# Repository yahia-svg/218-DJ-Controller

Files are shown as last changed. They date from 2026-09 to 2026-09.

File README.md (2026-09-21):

# 218-DJ-Controller
A fully DIY DJ controller. 

**Introduction**
---
`A brief intro about the project and the repository.`
<br>
This is a fully DIY DJ Controller. This repository includes the general 3D design of the DJ controller, some unique independent components, the firmware that runs the device, and the schematic showing the circuit connections that power the DJ Controller. 
**Note:** This project is not complete yet. As a result, you may find missing components and designs still under development.

**Project Status**
---
`This section describes the status of the project and the progress made so far, as it is yet to be completed.`
- The project is still under development; the current version only includes the initial designs and operating systems.
- As expected, a working prototype has not been built
- Currently, the full 3D design and the schematic diagram.

**Materials Table**
---
`This section has a table including all the data about the electronic components needed for building this DJ Controller. The table lists the number of pieces needed for each component (quantity); the type of component/actuator (Type); the exact model name for the component (Module); the total amount of money spent to buy the full quantity of the component (price) aka if we're buying 20 buttons, the "price" is the total money needed to buy all 20 buttons; and finally the link address where you can buy this exact component online (Link).`
| Quantity | Type | Module | Price | Link |
|---|---|:---:|---|---|
|1|Microcontroller|Teensy 4.1 Microcontroller|57 USD|https://devboardsmarket.com/products/teensy-4-1|
|2|Multiplixer|74HC4067 16-Channel Analog Digital Multiplexer|3 USD|https://www.ram-e-shop.com/shop/kit-multiplexer-744067-74hc4067-16-channel-analog-digital-multiplexer-breakout-board-8009|
|15|Rotary Potentiometer|R0902N rotary potentiometer 10kohm|5 USD|https://ar.aliexpress.com/item/1005007976451892.html?gatewayAdapt=glo2ara|
|6|Slide Potentiometer|b103 rotary potentiometer 10kohm|6 USD|https://microohm-eg.com/linear-slide-pot-10k-103-mixer-style-88-mm-body-3-electrical-pins-2-mounting-lugs/|
|4|Rotary Encoder|EC11 Rotary Encoder|2 USD|https://www.ram-e-shop.com/shop/pot-ec11-rotary-5pin-20mm-ec11-rotary-encoder-with-push-button-switch-5pin-20mm-silver-9624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|
|2|Bearing|608ZZ Shielded Miniature Ball Bearing|0.5 USD|https://ampere-electronics.com/product/608zz-shielded-miniature-ball-bearing-8x22x7mm/|
|20|LEDs|NeoPixel 1-bit WS2812 5050 RGB LED Driver|13.4 USD|https://www.ram-e-shop.com/shop/kit-ws2812-single-neopixel-1-bit-ws2812-5050-rgb-led-driver-development-board-8258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|
|50|Resistors|10 kohm Carbon Resistance 1/4W|0.5 USD|https://www.ram-e-shop.com/shop/carbon-resistance-1-4w-price-per-4-resistors-9506#attr=314|
|50|Resistors|220 Carbon Resistance 1/4W|0.5 USD|https://www.ram-e-shop.com/shop/carbon-resistance-1-4w-price-per-4-resistors-9506#attr=314|
|20|Capacitor|Ceramic Capacitor 100nF - 400V (104J400V) Disc 10mm|3 USD|https://ampere-electronics.com/product/ceramic-capacitor-100nf-400v-104j400v-disc-10mm/|
|10|Capacitor|Ceramic Capacitor 1uF - 630v (105J630V) Disc 20mm|1.5 USD|https://ampere-electronics.com/product/ceramic-capacitor-1uf-630v-105j630v-disc-20mm/|
|5|Capacitor|Electrolytic Capacitor 100uF - 50V|0.1 USD|https://ampere-electronics.com/product/electrolytic-capacitor-100uf-50v/|
|5|Capacitor|Electrolytic Capacitor 100uF - 50V|0.1 USD|https://ampere-electronics.com/product/electrolytic-capacitor-10uf-50v/|
|1|Power Supply|Wall Power Adapter 5Vdc 3A|5 USD|https://www.ram-e-shop.com/shop/rpi4-adaptor-onoff-wall-power-adapter-usb-type-c-output-5vdc-3a-with-on-off-switch-7840|
|4|Wires|2mm Electric Copper Wire 11 AWG, 1 Meter ElSewedy Electric|3 USD|https://fluxelectronix.com/shop/electric-copper-wire-2mm-15-awg-1-meter-el-sewedy-electric/|
|1|Screws|Bolt +M3x08 mm (100 Screws/bag)|1 USD|https://www.ram-e-shop.com/shop/nail-3x08mm-bolt-m3x08-mm-100-screws-bag-6546|
|2|Connector|Pin Header Male 1x40|0.1 USD|https://www.ram-e-shop.com/shop/ph1-1x40-male-ph1-pin-header-male-1x40-straight-2-54mm-5808|
|2|...|Breadboard 830|1.2 USD|https://www.ram-e-shop.com/shop/bb01-bread-board-bb-01-breadboard-830-tie-point-6143|
|43|Buttons|DS-430 Push Button Momentary Switch Square Shape 2 Pin|4 USD|https://makerselectronics.com/product/ds-430-push-button-momentary-switch-square-shape-2-pin/|
|1|Connector|Dupont Crimp Connector Kit - 310 Pcs|2.5 USD|https://fluxelectronix.com/shop/dupont-crimp-connector-kit-310pcs/|
|1|Socket|Audio Microphone Female Socket|0.1 USD|https://lampatronics.com/product/audio-microphone-female-socket-jack-japan-6-35mm-6pin-stereo-pj-609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|
|1|Switch|Metal Switch On/Off 12mm|1.5 USD|https://lampatronics.com/product/audio-microphone-female-socket-jack-japan-6-35mm-6pin-stereo-pj-609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|
|1|Cable|Micro USB Cable for Arduino|0.5 USD|https://fluxelectronix.com/shop/micro-usb-cable-for-arduino-30cm-length/|
|2|Connector|Female USB Connector Type(A) DIP|0.1 USD|https://fluxelectronix.com/shop/female-usb-connector-type-a-dip/|
|1|Connector|Female DC Power Plug to 2-Pin|0.1 USD|https://fluxelectronix.com/shop/female-dc-power-plug-to-2-pin-screw-terminal/|
|1|Connector|AUX 3.5mm Female Jack|0.1 USD|https://makerselectronics.com/product/aux-3-5mm-female-jack-solder-connector/|
|2|Magnetic Rotary Position|as5047d|14 USD|https://www.alibaba.com/product-detail/AS5047D-AS5047P-Encoder-Adapter-Board-SimpleFOC_60824124421.html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|
<br>
**Extra Services Used**
---
`This section mentions the extra services or technologies that you will need to utilize to build the project and how/why/for what you will use them.`
| Type | Usage |
|---|---|
|3D printing|Joy Wheels and Performance Pads' Caps|
|CNC Cutting|Cutting the acrylic to form the body of the DJ ControllerZ

---

**Mechanical Analysis**
---
`This section showcases the 3D design of the whole device, allowing you to accurately analyze the mechanical sid of the project.`

This is the 3D model visualizing the design for the DJ Controller. The design showcases the different pads, potentiometers, and encoders.

**Electrical Analysis**
---
`This section includes a detailed analysis of the electrical side of the project through the multitude of schematic designs provided in the section, showcasing the wiring of the circuit and component placement (in the context of circuit connections`

This shows the schematic diagram for the circuit powering the DJ Controller


This shows the schematic diagram for the buttons used in the circuit powering the DJ Controller.


This shows the schematic diagram for the LEDs used in the circuit powering the DJ Controller.

--- 

**Component Analysis**
---
`This section consists of a table that showcases the unique components we used for our project (components); the unique feature available in our project that these components bring (function); and how these components operate or what process they follow to provide these unique features.`
| Component | Function | Operation|
|---|---|---|
|Jog Wheel|Mainly used to control playback|Rotation sends movement data|
|Tempo Fader|Can change track speed + BPM|Moving the slide controls the tempo percentage sent to the software|
|SYNC|Used to match decks easily and automatically|Software adjusts deck based on BPM Analysis|
|Play/Pause|Starts or stops playback|Rotation sends movement data|
|CUE|Sets a cue point and allows return to that point|Button controls sofware actions such as abilities preview|
|Loop IN|Sets starting point for a loop|Marks the beggining of a loop|
|Loop OUT|Sets ending point for a loop|Marks the end of a loop|
|Loop ON/OFF|Used to activate or deactivate loops|Toggles the current loop|
|Loop Size -/+|Used to control or change loop length|Button Changes beats|
|TRIM|Able to control input level|Changes chanell gain|
|HI|Able to control high frequencies|Boosts or cuts treble|
|MID|Able to control middle frequencies|Boosts or cuts vocals|
|LOW|Able to control low frequencies|Boosts or cuts bass|
|Channel Fader|Able to control deck volume|Vertical movement changes volume for chosen channel|
|Channel CUE|Able to preview a deck through headphones|Routes deck to headphones|
|Crossfader|Used to blend both decks (deck 1 and deck 2, aka right side and left side deck)|Controls both decks|
|Master Level|Controls output|Changes final volume|
|Headphone Level|Controls volume of what is heard through headphones|Adjusts headphone volume|
|Master Mix|Controls what is heard through headphones|Assigns each section different values|
|Beat FX Select|Choose effects|Cycle through effects|
|FX Parameter|Controls Effect Intensity|Turning changes parameters for effects|
|Beat -/+|Changes effect timing|Changes effect beat|
|FX ON|Used to activate effects|Toggles the selected effect|
|Smart CFX|Used to apply combined effects|Simoltaneous change of multiple effects|
|Smart Fader|Used as a helping mechanism to automate transitions|Performs changes while transitioning between decks|
|Smart Fader AUTO|Allows automatic transition activation|Excutes Smart Fader Behavior|
|MIC INPUT|Connect Microphone|Audio enters the computer interface|
|MIC LEVEL|Microphone level|Change microphone level|
|MIC ON/OFF|Enables Microphone|Mutes microphone|
|HOT CUE|Used to store playbook points|Works with predefined positions (CUE Positions)|
|PAD FX|Operates effects from pads|Each pad is used to activate a specific effect|
|BEAT JUMP|Used to jump through tracks|Move playback forward and backward based on beat amounts|
|Sampler|Used to play samples|Utilizes stored sounds|
|Performance Pads|Allows Multifunction controls|Behavior changes with selected mode|

---

**Assembly Guide**
---
`You can think of this section as a "Methods" section. Basically, it gives a general guide on how to build this project.`
<br>
**1. Get the electronic components that you will need**
You will need to get all the electronic components that we listed in the materials table above. In addition, it is really important that you get the same number of pieces if you wish to implement this project at the same scale we did.

**2. 3D printing and CNC cutting**
After getting the electronic components, you will be missing some pieces. You will have to get some parts printed first. These are the caps used for the pads and potentiometers. Sure, you could avoid using caps at all, and with that you won't have to print any parts, but having these caps significantly changes how your device looks visually (to the better, of course). Then, it is necessary that you build the body for the controller. We chose to build it using acrylic. If you wish to do the same, then relying on CNC Cutting is the most efficient method to build that body. After cutting the Acrylic into the desired shape, you will probably need to use heating mechanisms to shape into the final required shape.

**3. Placement and Wiring**
Now, you're finally ready to start building; all the things you need are ready. What you need to do now is get the body you're using and place the electronics in their designated places/locations as per the full 3D model provided above. Then, you should start wiring and connecting all the components with the help of the schematic diagrams we provided above.

**Repo Layout**
---
`This section gives you a quick and brief walkthrough of all these files you see in the GitHub repository and what you can expect to see in each file.`
<br>
-Mohamed'sJournal.md contains Mohamed's work and contributions to the device, which include feature selection, BOM, and 3D design of the device's body.

-YAHYA'SJOURNAL.md contains Yahya's contributions, which are mainly focused on the 3D design of the main body, including multiple rendering processes.

-Michael's-Journal.md contains Michael's contributions to the project, which include the initial 2D sketch of the device and writing this README for you to read.

-Moaz's Journal contains Moaz's contributions to the project, which mainly revolve around designing the electronic circuit powering the device by drawing a schematic diagram (like the ones provided above).

-Schem is a folder within the repository that contains all the schematic-related files.

-Zine 1 and Zine 2 are two visual methods of representing the project.

-Acrylic cuts is a folder that contains the acrylic sheet cuts that will be used in the device.
**Plans for next week**
---
`This section gives a brief idea of what we plan to do and accomplish within the next week.`
- Develop firmware
- Finalize Designs for 3D-printed components
- Run final tests to make sure the device is running and operating correctly.

**Expected Project Status**
---
`This section describes the results that we expect to achieve within the time span of the next week, after fulfilling our goals/plans described in the above section (Plans for next week)`
- 3D-printed components' design: Complete
- Circuit analysis: Complete and fully operational
- Project Progress Overall: Complete
- Next Step: IRL Prototype Building

**FAQs**
---
`This section includes the answers to the most commonly discussed topics within or ouside of your main community discussion topics.`
**Why build a DIY DJ Controller?**
<br>
If you love music, it's definitely a great investment. You will get to tune, mix, and use as many effects as you want on your favourite songs/music. In addition, you can just try and explore new stuff using this new device. Now, if you don't love music, it's still really fun to just play with it and do random stuff. Also, it's really cool; just imagine how cool it would be to play DJ for your friends when they come over or just give them the opportunity to play with it for a while. It's just super fun.

**I don't have much experience building stuff. Can I still build this?**
<br>
Definitely yes. We didn't have that much experience ourselves. In fact, I think that this is my first or one of my first ever hardware/electronics projects to work on. So, to answer your question, yes, you can build this yourselves (THis is not an overly optimistic future; it's actually totally realistic.

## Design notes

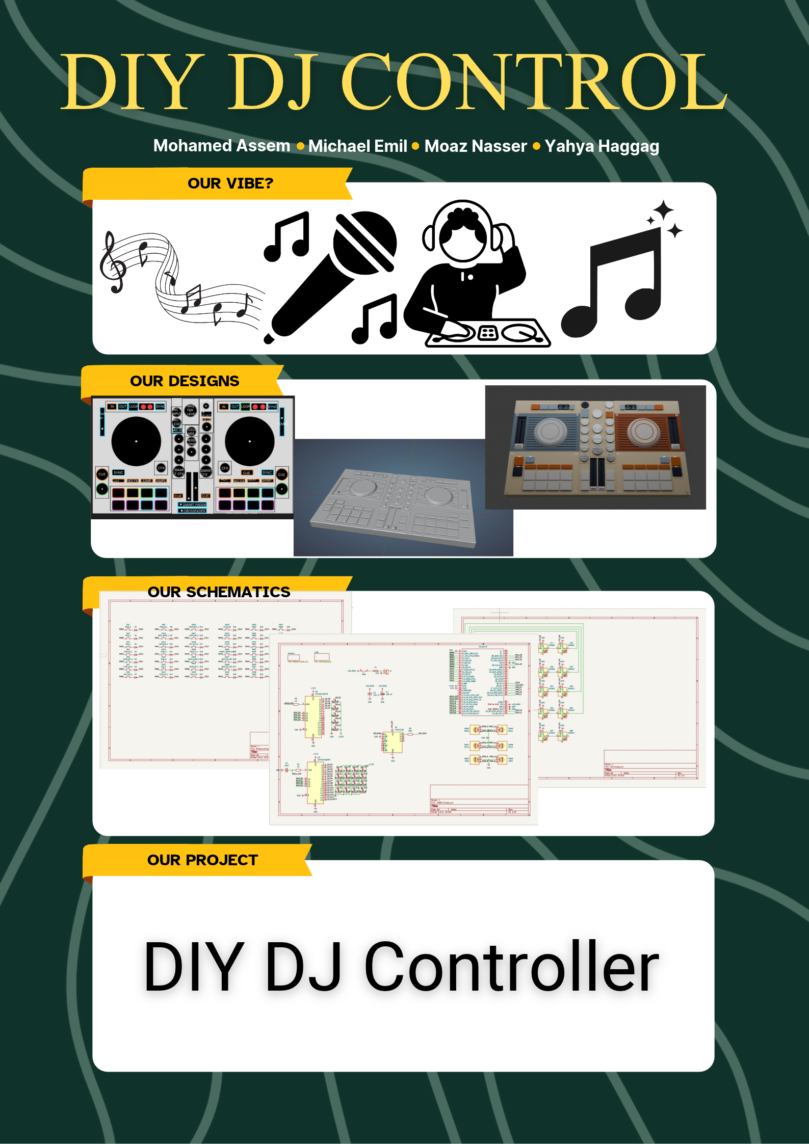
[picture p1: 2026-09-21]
Zine 1.png

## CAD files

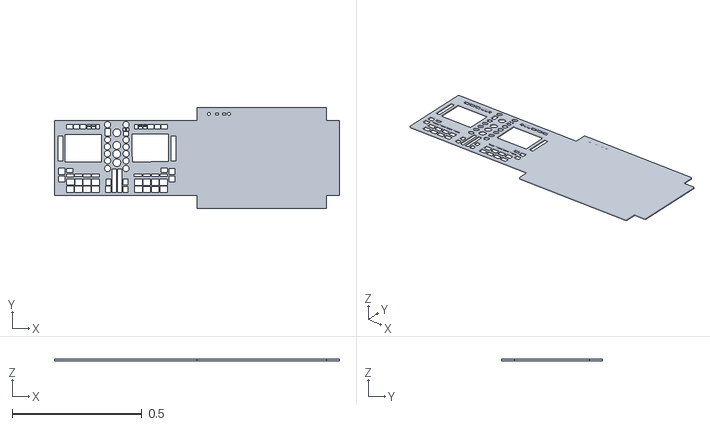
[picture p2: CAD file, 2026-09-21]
acrylic cuts/body.stl
1.10 x 0.39 x 0.006

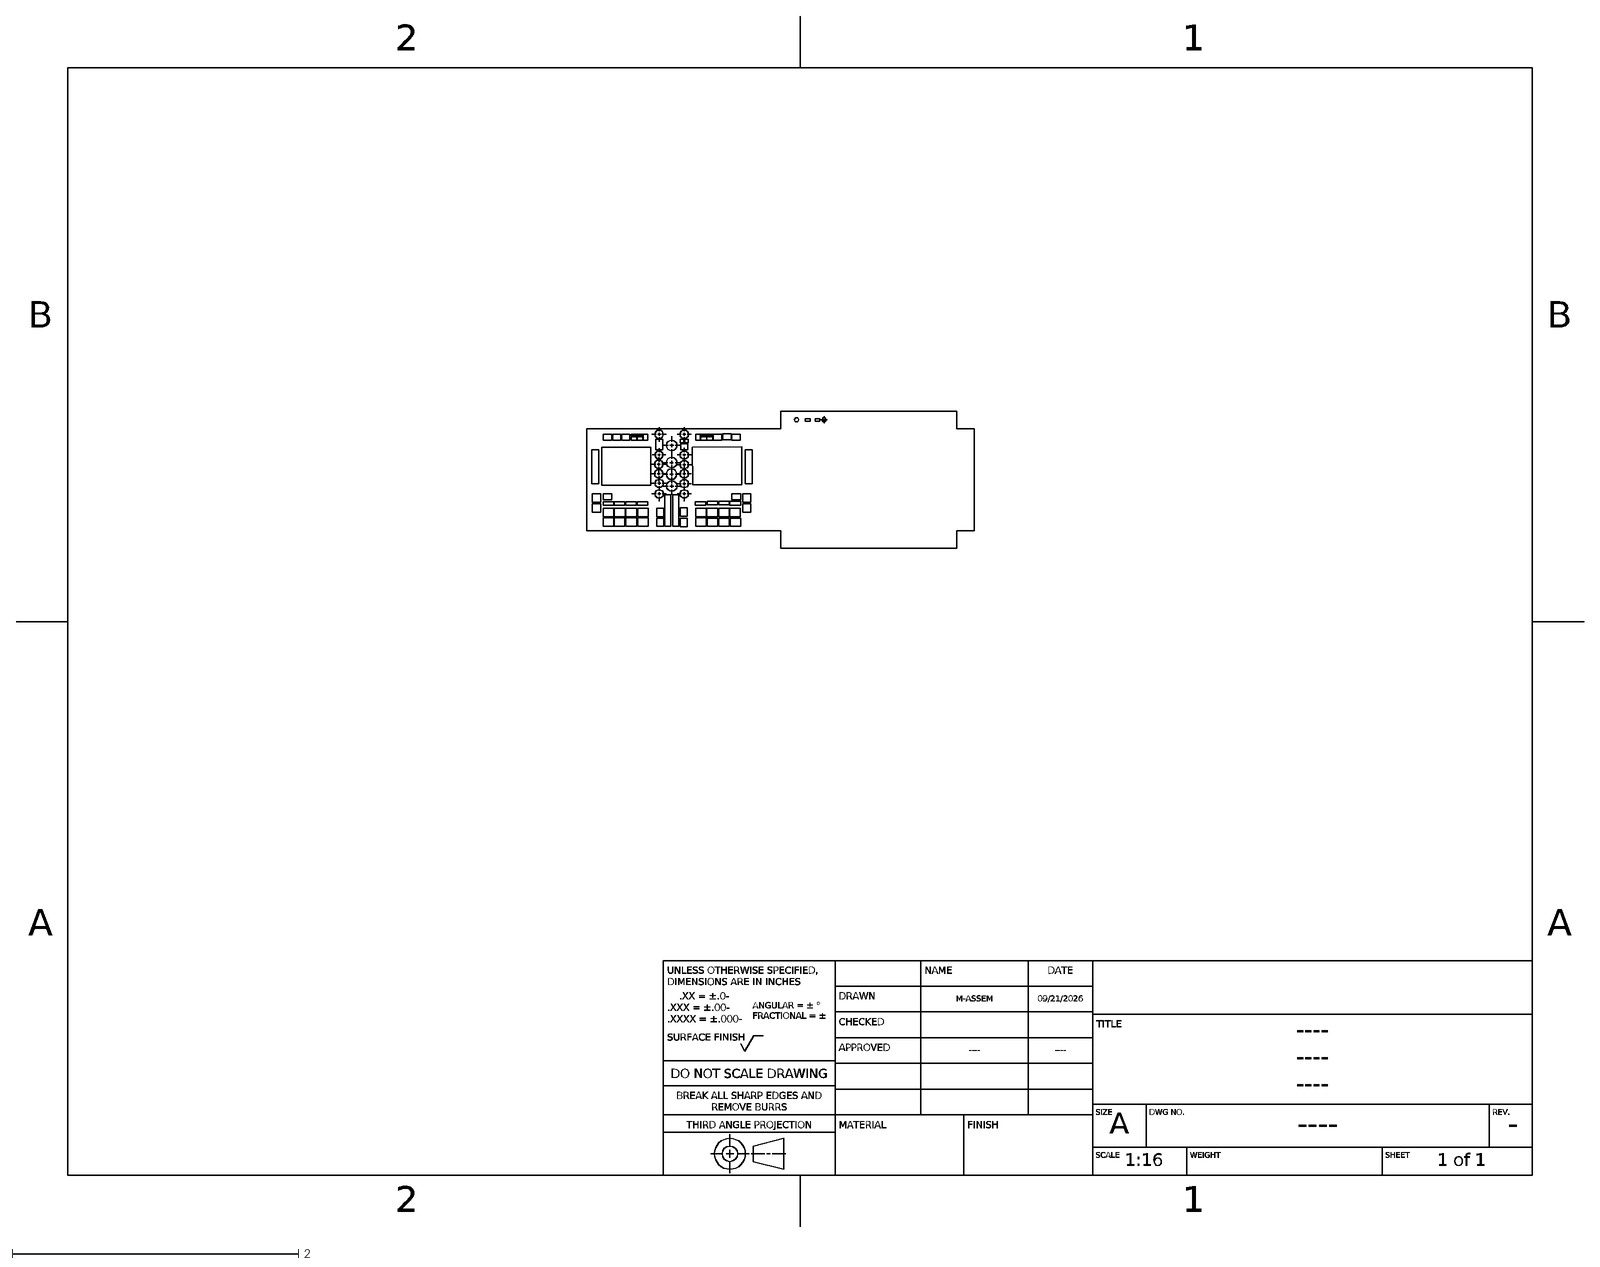
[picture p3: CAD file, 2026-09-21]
acrylic cuts/dj body.dxf
2
1
A
B
UNLESS OTHERWISE SPECIFIED, DIMENSIONS ARE IN INCHES
.XX = ±.0- .XXX = ±.00- .XXXX = ±.000-
ANGULAR = ± ° FRACTIONAL = ±
SURFACE FINISH
DO NOT SCALE DRAWING
BREAK ALL SHARP EDGES AND REMOVE BURRS
THIRD ANGLE PROJECTION
NAME
DATE
DRAWN
M-ASSEM
09/21/2026
CHECKED
APPROVED
----
MATERIAL
FINISH
TITLE
SIZE
DWG NO.
REV.
-
SCALE
1:16
WEIGHT
SHEET
1 of 1

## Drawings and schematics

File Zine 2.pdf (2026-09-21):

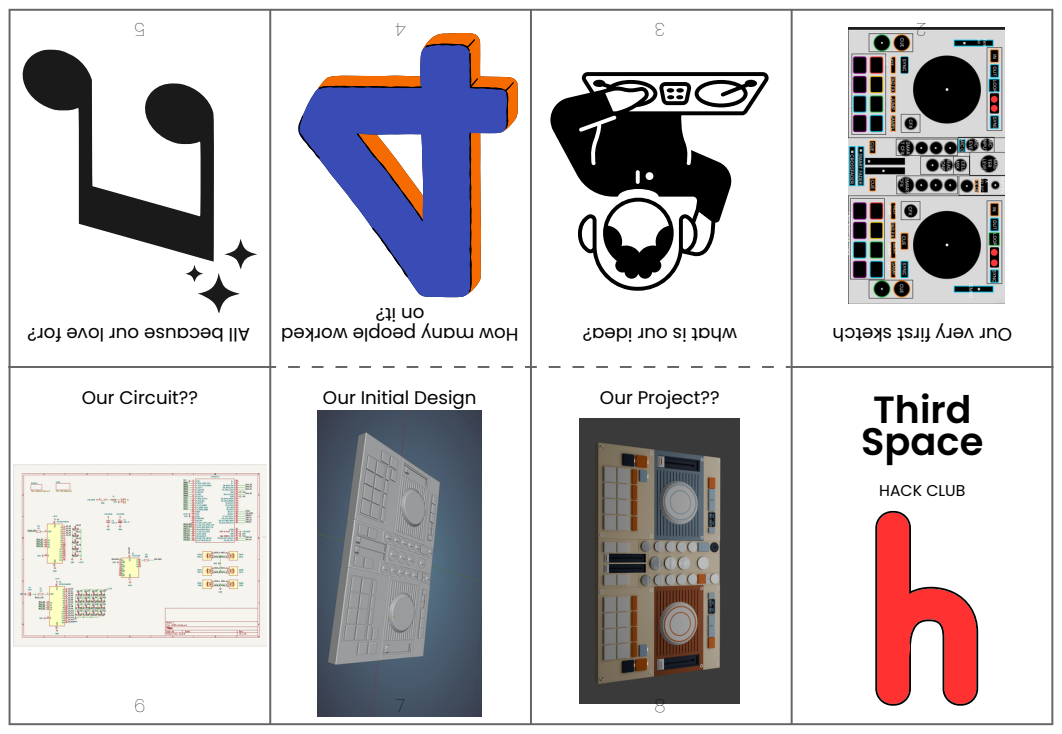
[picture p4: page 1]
Third Space; Our Circuit??; Our Initial Design; Our Project??; HACK CLUB

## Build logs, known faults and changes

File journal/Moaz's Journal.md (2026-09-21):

### 21-9

From all of the work that I can do in this project, I really wanted to make the schematic. It's a relatively new yet a familiar process, I love how intrigued it is, when you do the connections and try to optimize the space and how clear it is, and also I have some small experience with KiCad so it was easy to start working from the beginning. The bill of material wasn't my own mission, yet I helped in it a little bit. As our goal was to create a controller with physical controls and similar to professional ones, it was actually a last minute idea that came to me and my teammate yahia at the same time, so we had to do it.

---

I had multiple problems that involved different solutions even before I started  actually working. My friend decided theta Teensy 4.1 MCU is going to be te best for our use case, as it was used in different audio and music based projects. Having next to zero experience I was struck when I didn't find the symbol for the Teensy in the KiCad default symbol editor. I want on a ([docuemented][https://lapse.hackclub.com/timelapse/hXlyyBR2OCXZ]) run that was resolved by me finding about KiCad symbol libraries, and that I can find any symbol by examining open source, user made symbols, a one that was very useful was [this one][(https://github.com/blackketter/teensy.pretty)] which held the entire library for the Teensy. Also I had 2 options which was either using one large schematic sheets, at the beginning, I found that using multiple schematics is confusing, so I chose the large one, but after working for a while, the sheet was crowded that I had to use multiple ones.

---
I analyzed the BoM, looking at how many buttons, LEDs and everything we need, which helped me plan the "pin assignment", it is summed up in this table:
| Teensy pins | function |
| --- | ----- |
| 0-6  | Button matrix rows |
| 7-12 | Button matrix columns |
|14 | MUX 1 |
| 15 | MUX2 |
|16-23 | four EC11 encoders |
|24-27 | 2 JOG wheels |
| 28 | LED Data |
| 29 | Button Matrix column |
|36 - 39 | MUX select |
| 3 | power stuff |
 
 ---
 So I had some (13) free pins, as it was related to onboarding.
 ---
 While making the schematic I used net-based connections, which are about using net labels rather than actually connecting the pins. That meant I could connect modules that were at opposite sides of the sheet.
 ---
 For the power section, it began by making a two-pin connector, it was made for external regulated 5V supply. I of course added capacitors for power filtering  and decoupling, as these errors could be fatal to the whole thing.

The controller has ore analog controls than the teensy has convenient analog inputs. Thus I had to use a technique called **multiplexing**, it is about running energy through a grid but only lighting one row at a time, if we had to make multiple rows light at once we would flicker them so fast that the eye won't notice.
To apply this without complex circuits I used analog multiplexers, I looked for multiple options but the 16-channel CD74HC4067.

---
MOst of the controls and inputs are based on potentiometers, mainly rotary and slide ones, these potents connected to the multiplexer channels trough the center correction or the wiper. While the common output goes to the Teensy analog input, of course capacitors were added for filtering.

Now, remember my example for how grids optimized the energy, this goes the same for a grid of buttons. thus, I used a 7x7 button matrix for all the button controls.

Each button received its own 1N4148 diode, these diodes helped prevent unwanted electrical paths, commonly called ghosting, when multiple inputs are registered.

The matrix positions were based on actual controller functions.
with these buttons including:
SYNC, PLAY, CUE, LOOP IN, LOOP OUT, LOOP ON, HOT CUE, PAD FX, BEAT JUMP, SAMPLER, MIC ON, FX ON, SMART Fader Auto, Beat FX +/-
Performance pads.

---

I used rotary encoders like the EC11 (four of them) to control some stuff like loops or FX Selection, and the teensy supported internal pull-ups for these ones which is nice.

---

Of course, there isn't a DJ without jog wheels, They were independent, with their own power and quartet control,

There were 25 addressable RGB LEDs, which are necessary for any good looking DJ. These indicate states, I had to get them their own bus buffer, which was a pain in the ass, For some reason the Symbol for the SN74AHCT 125, it was some weird triangle logic thingy and I hat to scour githubs to find the correct thing, which was even legacy (.lib).

But at last, I was able to add it and connect it to the system. The purpose of it is to translate the 3.3V to 5V logic signal. this completed the LED data interface.

I connected it to the LEDs in a daisy chain (or more morbidly a human centipede)

---
 That's all for now regarding the schematic.

---
I worked for a little on some other miscellaneous stuff, like the BoM by adding control caps and though about making a zine, brainstorming with my teammate.

---
After remembering ow stupid I am and that there is something called ERC in KiCad and found several problems with the old one, making it obsolete.
From stupid problems such as duplicate reference (U2) and shorting a 3.3V pin to GND in Teensy, to much more bigger problems such as not using global labels which disconnected all the sheets from each other, making them completely ineffective, and swapping the ground and logic supply for the entire LED grid. I also added more coupling and filtering to make this circuit more resembling to real life.

---
A final change for today, I replaced the rotary encoders, for the jog, with magnetic rotary position sensors which will increase efficiency. I also replaced the Teensy 4.0 in the schem with 4.1, I used 4.0 initially because it looked simpler.

---
Journal Links:
https://lapse.hackclub.com/timelapse/9HSuw6ijgOAE
https://lapse.hackclub.com/timelapse/OjnOfFxcyOtB
https://lapse.hackclub.com/timelapse/4eUOfzpiVSXv
https://lapse.hackclub.com/timelapse/dJgap3DlKfkE
https://lapse.hackclub.com/timelapse/16tVSgQC2hcQ
https://lapse.hackclub.com/timelapse/FWIT91Rc2bJZ
https://lapse.hackclub.com/timelapse/ID_0dAGPpfu-
https://lapse.hackclub.com/timelapse/Rr1lFko1LJV_
https://lapse.hackclub.com/timelapse/GRKJxnAV0saB
https://lapse.hackclub.com/timelapse/HdR1McedKOW6
https://lapse.hackclub.com/timelapse/hXlyyBR2OCXZ

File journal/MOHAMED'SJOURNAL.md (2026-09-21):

---
Title: "218-DJ-Controller 3d Design"
Author: "Mohamed Assem"
Description: "A DIY DJ controller"
Created_at: "2026-09-20"
---

# Septemper 20 : 
total time spent 11.1 hrs <br>

lapse links: part1: https://lapse.hackclub.com/timelapse/nAk_ChLudF3S <br>
part 2 : https://lapse.hackclub.com/timelapse/eGmrk4pUCh6i

At first I had to search about every thing about these DJs that are spread around the world right now, focusing on models that are having good features with keeping the cost as a variable like DDJ FLX4.
I watched some videos explaining each button and each feature with explaining the way it works and importance. So I started to decide our DJ features taking some common features and added some like the cue button and the 16 performance pads with leds changing their intensity and colors. 
I had to document all my search in a notion file so the team can continue on it, so was documenting part by part. Documenting things like a piece of schematic diagram to a mixing module. <br><br><br>
 <br><br><br>
then started to search about same DIY projects that my help and they were pretty good start for the materials. Credits:
https://github.com/mandiclab/djc-diy <br>
https://github.com/jueta/DIY_DJ_Controller

then I had to start the BOM and started with the microo controller whcih here i used some of chat gpt to find a merchant to the teensy 4.1 in egypt as it was hard searc, as after alittle bit searching i've fornd that the teensy 4.1 is very suitable microcontroller to this project as it was espicially made for real time audio processing.<br><br><br>
 <br><br><br>
I started writing the BOM which was a little bit challenging at first to know what should be added and which module, but i knew the required things like rotary potentiometer and the slider ones by thier quantities from the 2d design imagination for it as it was too helpful to imagine the 3d designa nad the materials by thier quantines.
then i had 2 multiplexer that would connect all of this potentiometer to control it. MOst of the materials was selected from egyptian merchants to control the prices and keep it cost effecient as it is one of our goals.

then the rotary & slider potentiometers to the faders of the volume and these stuff but for the jog wheels we used the rotary encoders that can rotate 360 degrees wihtout any specific range like the rotary potentiometer.
WS2812 whcih is a led module that can be controlled by the MCU controlling the light inetindty and colors so it was actully pretty expensive but i sac this to this nice try.
used a wall adapter 5 v as the main Power supply unit to the DJ as it will not be enough connecting it by usb to laptob. also used a bearing that will be responsible to the rotation of the jog wheels as it offer frictionless motion. some wires and breadboard to help in the connection of all the project. right now I'm tryning to decrease the cost and search for extra materials we will need. and here is the link of excel sheet : https://docs.google.com/spreadsheets/d/1D9nlrNGDWYnSP95DjBncR3g8EgScZhrTWujonI9YDiM/edit?usp=sharing
each element written beside it the price in usd dollars and has the link to the website. Then the main body of the DJ will be made of acrlyic as if we will print it it will be very expansive and hard to find some printers in Egypt with this same size unless cutting it into many parts so using acrylic is a good choice although I didn't make each face to be alone its just like a foldable box. so  how will be used in terms of the acrylic by heat will lean it and make the acrylic bends and make different degrees, so i mad a 3 min diagram to the dimensions on the painter to visualize all of it. <br><br><br>

<br><br><br>
so an example for the acrylic rotation i've made an acrylic sheet to make like a vortex motion to the water <br><br><br>

<br><br><br>
this was made by nearing a hot flame to the acrylic then leave it to cool done after reshaping it the acrylic sheet will be 6mm thickness and cut on a local cnc router machine. I designed it on onshape with dimension of 500*290 mm for the whole project then i started to draw the buttons and faders based on a 2D image to keep everything in the correct position and the same ratio then after drawing a part i used the mirror entities to make sure it be centered and balanced all the shapes ranged between 17 to 30 mm in their dimensions, which is based on the potentiometers and the other things so after adding like 15 rotary potentiometer and 4 slide potentiometer. <br><br><br>
<br><br><br>

and at the end of this design I just get the drawing file and exported it into dxf file, at first i was afraid from the spaces between each other but i relized that it will be relative the only factor is the opening is equal to the switch or not so i manged to make all of them measured and aligned together <br><br><br>
 <br> <br><br>
then at the final edit i added opening to the sockets of the female microphone/AUX also the power supply dc plug female and last thing to have a 2 usb ports to be easily connected to laptop and a speaker if wanted  
<br><br><br>
 <br><br><br>
then i started to optimize in the BOM File and decrease the amount of money was not that much but in next version can be reduced. and searched for the caps and performance pads instead of printing it as it will be much more expensive. havenot found alot and the only store found in it didnot have that much sizes so i just chosen the nearest one and I think it will be enough. <br><br><br>
 <br><br><br>

also i've added all the ports we will need AUX 2 usb ports and the dc plug for the 5volt adapter for this version very good we still have to work on the firmware and finalize the assets like stls that 'll be printed and the dimensions are correct.

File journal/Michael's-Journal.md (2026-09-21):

---
title: "218-DJ-Controller 3d Design"
author: "Michael"
description: "A fully DIY DJ controller"
created_at: "2026-09-20"
---

# September 20: 

**total time spent 4 hours** <br />

First, I was working on the design for the DJ controller using figma. I started with choosing the initial positions of all
the different controls in order. I divided the Controller into 3 sections: 2 decks on both the right and left sides of the
controller, then there was the mixer placed as the middle section. I designed the whole controller to be 600mm wide and 350mm
long, allowing us to make each of the decks to be 240mm wide and the mixer to be 120mm wide. Inside deck 1 (the left side deck)
I added the Performance pads including 8 38*30mm Push button momentary switch and 4 18*12 push button momentary switches. 
Then I added one rotary potentiometer forming the smart CFX, a slide potentiometer to form the Tempo, and a Loop consisting of
5 diifferent pads. Finally I added the rotary encoder. I repeated almost the same process for deck 2 (the right side deck).

After that I started working on the mixer (the middle section between deck 1 and deck 2). I added the Beat FX consisting of 2 
pads and 2 rotary potentiometers. Then I added the Mic Input including 2 rotary potentiometers and one pad. Then, I added the 
Master consisting of 1 rotary potentiometer. Then I added the Level and headphones controls including 11 rotary potentiometers
and 2 pads. I then added 1 sliding potentiometer for the smart fader and 1 other sliding potentiometer for the crossfader and 2
extra potentiometer for some extra functions.

After finishing the initial design, I worked on improving the design. I divided the DJ controller into sub sections, allowing 
for easier navigation. Second, I started adding the names of each subsection, ensuring the improved navigation, then I added
the names of most pads and potentiometers, providing further improved navigation for the rest of my team and especially my friend
responsible for turning this design into a 3D model. 

For better visual representation, I added colored strokes to most pads and potentiometers representing the RGB lighting effects
of each function, emitating what will be implemented in the actual irl device, this was represented with colors including red, blue,
green, yellow, orange, purple, and gray. I then started adding a corner radius change to pads, this used different corner radius
changes, some valued at a 5% change and some valued at a 3% change. This happened with the goal of providing the closest visual
representation of the irl device. 

Now, for further functional navigation, I started adding small white circles for rotary potentiometers showcasing the actual 
size and placement position of the actual actuator inside of the 3D printed visual component. Same thing happened for the sliding
potentiometers, as I added small squares representing the actual actuator again.

# September 21: 

**total time spent 6 hours** <br />

I was mainly working on the README today. I spent a lot of time- I think 3 hours or something like that working on producing a high-quality README. In the README, I first wrote a quick introduction with the goal of giving brief context to the reader about what this project is and what this repository is. I then wrote about the project status, showcasing the progress that we have achieved so far. I then built this table that lists down all components or electronic parts that are used in this project. The table was really comprehensive as it had all the important information including the name of the componenet, the quantity used, the module for this specific component, the total price for each purchase and the lnk for boys those parts online.

I then wrote the (extra services used) section which had a table that included the extra tech you might need to build this exact project, such as 3D printing tech and CNC cutting tech. After that I wrote the Mechanical analysis and electrical analysis sections. The mechanical analysis section helps readers get a really good idea and an opportunity to deeply analyze our project from the mechanical side through this section. A detailed 3D model of the whole build was provided in this section to further improve reader understanding. The second section here was the electrical analysis section. Simillar to the the mechanical section, this section aimed to give people a good look into our electrical system. To furter support this we have multiple schematic diagrams to support greater understanding.

We then have the component analysis section, which is basically a table that contains all the unique componenet that we implemented in our project in addition to the features that have to offer us and the technology behind it.

I then wrote the (Assembly guide) section, which gives a brief guide on how to build this same project. Then I wrote the (reop layout section) which gives a nice description of what each file/folder in the repo does and just giving an overall good idea of the repository.

After that I added the (plans for next week) section which, as the name implies, discusses our plans for completing the project within the upcoming week. Then I wrote the (Expected Project Status) section which talks about the results that hope to achieve . I then wrote one final thing, which is the FAQs section. A fun section talking about some expected to be common questions and so on about our project.

To finalize this nice (hopefully) README, I added some formatting and styling effects for the README to have a better and more professional look. I also added a brief description of each section right at the beginning.

Doing another very important thing, my team wanted to have a visual representation that would help promote the project. For that reason, we opted to use a Zine. I was the one who designed the zines (we designed 2 zines, both are available in the repository). Though to be honest, I don't think the zines are that good, I didn't design a Zine before and it's actually my first time ever dealing with one, but I am trying to look at more good choices and hopefully improve them by next week. Honestly, I tried to search it up on the internet but I didn't find what I am looking for. But I found this YSWS were having a Zine is mandatory or smth like that so there are a lot of Zines that I could check out. So, that's exactly what I am doing now.

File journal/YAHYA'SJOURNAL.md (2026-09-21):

---
title: "218-DJ-Controller 3d Design"
author: "Yahya"
description: "A fully DIY DJ controller"
created_at: "2026-09-20"
---

# September 20: 

**total time spent 10.25 hours** <br />
[lapse](https://lapse.hackclub.com/timelapse/QtJcBVnucqxT)

Okay so first and foremost, I need to identify the Design style for this project so I gain a general understanding of how I want this project to look like. <br />
The first design style that came to my mind is a mix between 80s tech and futuristic tech because I find the mix between modern electronics and old machinery very intriguing. <br />
This kind of reminds me of the movie "back to the future" which blended 80's engineering with futuristic tech for the delorian.<br />
Actually, speaking of back to the future, I remembered the flux capacitor for the Delorian, and I could use that as the base feature for the controller and design the whole controller over that. <br /> 
testconcept1
I made this 3d basic design on blender with a flux capacitor in the middle to better explain the concept I was talking about. <br /> 
I think it's definitely an interesting concept and I find that it looks cool, but right now it just looks super unfinished and boring<br /> 
Overall, I really like the LEDS but I'm thinking of taking more inspiration from old tech when it comes to assembly and technical features because I want to give this an accurate skeuomorphic design, so I need to familiarize myself with older even obsolete design principles <br />  

First I want to research different models of DJ controllers in order to choose the layout that I find most appealing. <br />

okay so after browsing for some time I think it's best to follow the same general layout as the DDJ FLX 4 so I will base the next designs on it. <br /> 

As I was researching old tech I found this: <br />

the speaker design really caught my eye, I will probably add horizontal lines like that around the jog wheels <br />

I also found this old boombox and I really like how the design almost entirely consists of square panels and slightly beveled cubes so I will also probably try to emulate this in my design <br />

For the color palette I want a cream color an orange color and a light grey and a light blue for the led's and more modern features <br />

I found this color palette on [colorany](https://colorany.com/color-palettes/retro-computer-color-palettes/) It's inspired by Windows 3.1 Color palette <br />

Texture is also very important <br />



based on this chart I think I will use fuzzy skin 0.1 mm thickness with classic noise <br />

i will now draw a couple of very basic sketches on krita that incorporate these design features based on this layout made by my teammate michael <br />

So my teammate michael made this layout initially:

However, I thought that the middle section was very messy so i started first with the part on the left and i made a very basic sketch to help imagine what the 3d model would look like  I didn't finish it though because I felt like I could dive into the 3d straight away and save time so I made this:

I tried to really focus on having many squares so I turned the round on/off and cue buttons to squares and i placed them slightly outside the area where the hot cues were. I also split the jog wheel into two wheels a large inner wheel and a more precise outer wheel and i added these extrusions on the sides so that it would be easier to move for precise movements.
I also used the same modular design from the forementioned boombox where each set of buttons are in their own square island. and I created 3 main islands. and for this to be just a little more futuristic I decided to add small LEDS in the in and out loop buttons and to give them a more unique shape. As for the slider, I mostly stuck to the same design as the one in the boombox. 
By the time I've finished this design my teammate Michael has already made an improved version of the layout with much more symmetrical features:

Therefore, I moved onto designing the features in the middle but before I copied the layout I decided to change the position of the "mic on" button by shifting it up one position so it match the position of the fx select and fx on buttons since they were also square thereby making the design more symmetrical overall. After that I created this design:

I ended up changing the layout again but this time I removed the right cue button since it ruined the symmetry, and I extended the length of the sliders on the bottom so they would match the sliders on the top because the size in the layout was out of stock, I also shrunk down the crossfade and smart fade buttons so they would take less space since the middle was extremely crowded, I made sure to match their widths with the width of the cue buttons for better uniformity throughout the design. Finally I removed 2 of the cfx buttons because they were duplicated.
I was really proud of this design and when I showed it to my teammates, they also liked it a lot. At the time, I thought It had the perfect balance between sophistication and readability. But little did I know the Solid shading view tends to be very misleading in terms of expressing detail. 
Now for texturing and colors, I've decided to apply the color palette to the Layout my teammate gave me which was pretty easy since he color coded buttons based on similarity in function and visual distinction. I used the orange and blue for special buttons and I gave the basic controls like the jog wheel and hot cue buttons a very basic grey color and I gave very common buttons and the inside of the sliders in the navy blue color I've previously chosen because it creates very strong contrast with the beige background of the controller which makes these buttons easier to spot. For the texture I decided to go mostly with normal smooth 3d printed walls for almost the entire controller except for the island under the jog wheels where I used a rubber texture to represent fuzzy skin 3d printed pieces at a 0.1 mm thickness to create additional visual depth. and this is what that looked like.

This is when I realized that this design was incredibly bland and boring, so I've decided to add a lot more details until I came up with this:
toprender
One thing I wish I could've added is translucent buttons like this 

I tried really hard to achieve this but my version wasn't smooth like the picture 

Finally I have to say I'm really proud of this design and my teammates like it to so we've decided we're going to use it.

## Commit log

2026-09-20 Added the first version of my journal.md
    It discussed the search and documentation and the bom files at the first version
2026-09-20 Create Folder for schematic upload
2026-09-20 Upload Schematic files
    [218DJ.kicad_pcb, 218DJ.kicad_sch, Buttons.kicad_sch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]
2026-09-21 Update Schematic fixing errors (consult journal)
    [218DJ.kicad_sch, Buttons.kicad_sch, LED.kicad_sch]
2026-09-21 Update schematic with magnetic rotary sensors and updated board
    [218DJ.kicad_sch]
